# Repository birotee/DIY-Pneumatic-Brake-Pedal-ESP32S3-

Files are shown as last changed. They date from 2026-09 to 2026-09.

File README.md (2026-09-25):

# Jack Pedal

ESP32-S3 pneumatic brake controller using an ADS1220 and a 3.3 V, 0.4-2.4 V, 0-10 bar pressure sensor.

## Build photos

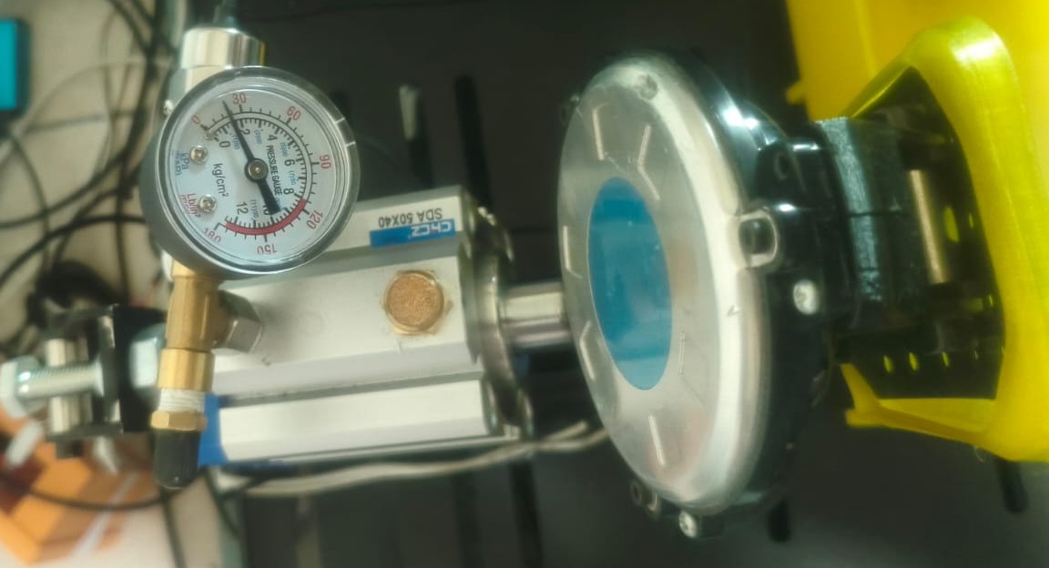
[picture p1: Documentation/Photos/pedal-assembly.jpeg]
Pneumatic brake pedal assembly


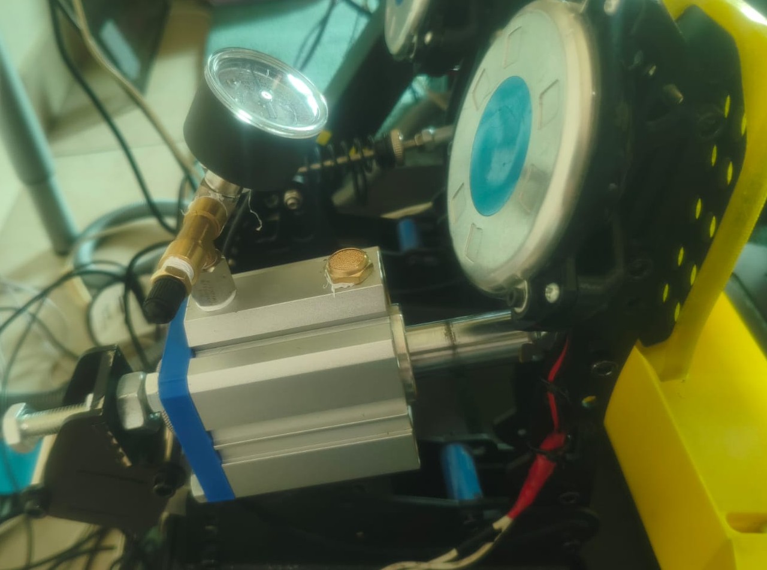
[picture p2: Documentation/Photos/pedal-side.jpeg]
Side view of the pneumatic cylinder and pedal


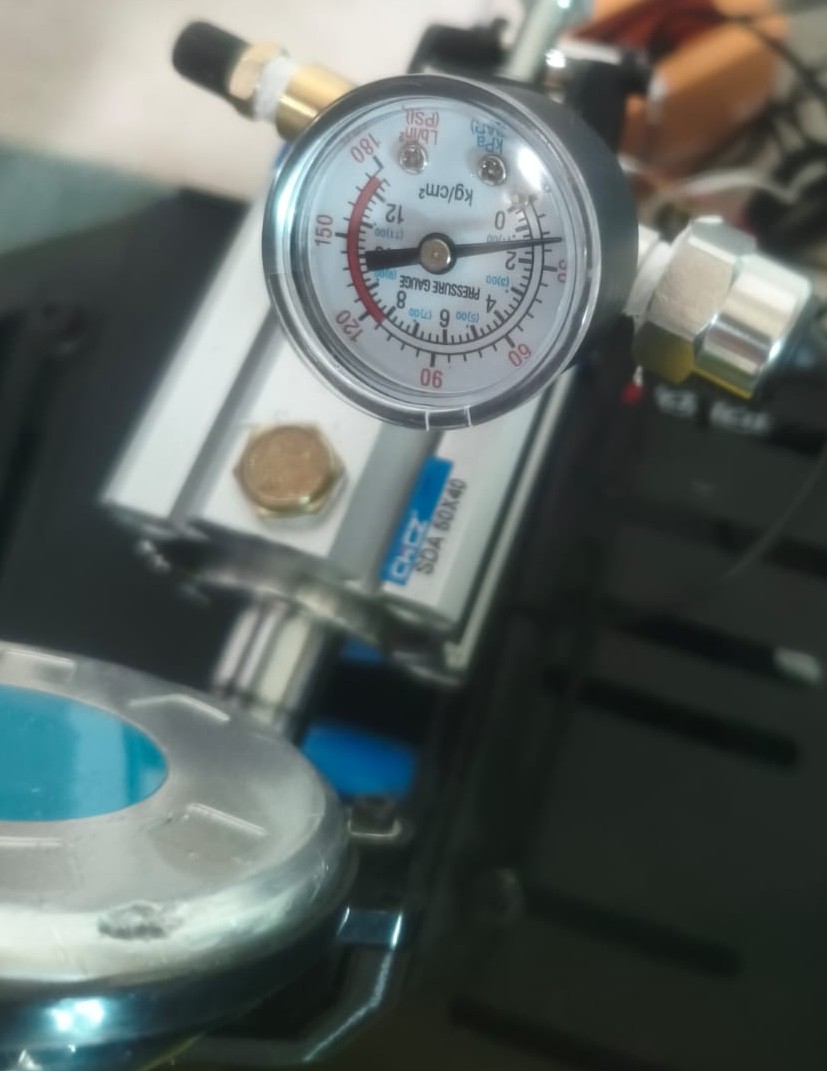
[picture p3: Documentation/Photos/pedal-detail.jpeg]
Pressure gauge and cylinder detail


## Files

- `JackPedal_PC/`: Arduino firmware and bundled ADS1220 library.
- `JackPedalControl.exe`: Windows calibration app.
- `JackPedalControl.cs`: app source; run `Build-Windows-App.ps1` to rebuild on Windows with the .NET Framework compiler.
- `Documentation/`: setup instructions and wiring PDF.
- `Enclosure/`: prototype 108 x 108 x 50 mm enclosure, STL files and editable OpenSCAD source. Read its fit limitations before printing.

## Wiring

| ESP32-S3 | ADS1220 |
| --- | --- |
| 3V3 | AVDD, DVDD, REFP0 |
| GND | AGND/AVSS, DGND, REFN0, CLK |
| GPIO10 | CS |
| GPIO9 | DRDY |
| GPIO13 | SCLK |
| GPIO12 | MISO/DOUT |
| GPIO11 | MOSI/DIN |

Sensor power goes to 3V3, ground to common GND, and signal directly to AIN1. No signal divider. CLK and SCLK are different pins.

## Arduino settings (N16R8)

ESP32S3 Dev Module; Flash 16 MB; QIO 80 MHz; OPI PSRAM; USB-OTG (TinyUSB).
Disable USB CDC, MSC and DFU On Boot. Upload through the COM socket.
Keep all files in `JackPedal_PC/` together when opening the sketch.

## Use

Close Serial Monitor before opening the Windows app. Select the current COM port and connect.
Capture MIN with the pedal released, then capture MAX while holding the desired full-brake pressure steady.
Bottom and top deadzones each support 0-25%; click Apply to save them on the controller.
Defaults are 2% bottom and 8% top: full brake begins at 92% of the calibrated range.
Pressure readings remain independent of calibration and deadzones.
Connect the native USB socket to the PC for game-controller input; the brake uses the Y axis.

## Validation status

Sensor readings and USB gamepad detection were confirmed by the user before the deadzone update.
The Windows app builds and its parser/calibration tests pass. Deadzone arithmetic was checked independently.
The latest firmware includes a fix for Arduino custom-type prototype ordering and still needs a successful user compile/upload and pedal test.
The enclosure is a fit-check prototype; its mesh edges were checked but physical fit is unverified.

## Credits

Based on the Jack-Pneumatic project by LandoCode89.
The bundled ADS1220_WE library was written by Wolfgang (Wolle) Ewald; its source notices are retained.
No new license is assigned by this upload preparation.

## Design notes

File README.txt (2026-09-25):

JACK PEDAL - CURRENT WORKING FILES

JackPedalControl.exe       Windows calibration app (working COM-fix build)
JackPedalControl.cs        Matching C# source
Build-Windows-App.ps1      Rebuild the executable; close it first
JackPedal_PC/              Arduino sketch and required ADS1220 library
Documentation/            Wiring PDF and setup guide

START HERE
1. Read Documentation/Setup.txt and the wiring PDF.
2. Upload JackPedal_PC/JackPedal_PC.ino through the board's COM socket.
3. Close Arduino Serial Monitor, open JackPedalControl.exe, select the current port.
4. Capture released MIN, then MAX at your desired full-brake pressure.
5. Connect the board's USB socket to the PC for game-controller input.

This keeps the known-working code, including USB diagnostics.
Older versions and test sketches were moved to the workspace backups folder.
No calibration data on the ESP32 was changed by this folder cleanup.

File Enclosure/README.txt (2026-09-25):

JACK PEDAL - 108 x 108 x 50 mm OVERALL

Base: 101 x 101 x 47 mm. Lid: 108 x 108 x 11 mm.
The lid overlaps by 8 mm, giving 50 mm assembled height.
3 mm walls/floor/lid top. Slip-over lid, 0.5 mm clearance per side.
Secure lid with tape or an external strap; this is not a snap fit.

BOARD FIT
Expansion board assumed 83 x 83 mm, placed on four 4 mm raised supports.
Use insulating pads as needed and narrow cable ties through floor slots.
Do not tie across components or antenna. No fixed screw posts: hole spacing unknown.
ADS1220 (21 x 21 x 8 mm) mounts UNDER THE LID in the 23 mm wide cradle.
Use a narrow tie through the lid slots to retain it, plus thin insulating pad.
Orient lid so ADC avoids tall connectors on the expansion board.
Internal clearance above expansion-board supports is 40 mm away from ADC.
Reserve 12 mm below lid for ADC/pad/tie, leaving 28 mm locally above supports.
Earlier 60 mm assembled wiring WILL NOT FIT unchanged. Rearrange and measure.
USB notch is 62 mm wide and starts 12 mm above exterior bottom.
Check USB plug height/reach and wire bend clearance before full printing.
Sensor notch is 12 mm wide and starts 25 mm above exterior bottom.

PRINT
STLs use mm. Print base floor-down and lid exterior-face-down as supplied.
Suggested starting settings: 0.2 mm layers, 3 perimeters, 4 top/bottom layers,
15-20% infill. Designed without supports in supplied orientations.
Nonconductive filament only. Not water/dust sealed. Fit/thermal tests pending.
Both meshes passed closed-edge tests; physical fit is NOT guaranteed.
Print a partial-height base first to check board footprint and tie locations.

FILES
JackPedal_Base.stl and JackPedal_Lid.stl: latest 108 mm version.
JackPedal_Enclosure.scad: editable OpenSCAD source.
Layout.png: base/lid plan and clearances.
Mesh_Checks.json: mesh dimensions/check results.

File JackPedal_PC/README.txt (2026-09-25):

JackPedal PC - 3.3V supply, 0.4-2.4V output, 0-10 bar sensor

Open JackPedal_PC.ino with ADS1220_WE.h and ADS1220_WE.cpp alongside it.
Sensor supply + -> ESP32 3V3 (not 5V).
Sensor ground -> common GND.
Sensor output -> ADS1220 AIN1 directly. Remove the old signal divider.
Identify sensor wires from its label; do not assume the old sensor colors.
ADC AVDD, DVDD, REFP0 -> 3V3.
ADC AGND/AVSS, DGND, REFN0 and CLK -> common GND. CLK is separate from SCLK.
CS GPIO10, DRDY GPIO9, SCK GPIO13, MISO GPIO12, MOSI GPIO11.
All SPI and DRDY connections direct; no resistor dividers.

Reference 3.3V, gain 1, PGA bypass, SPI 1 MHz.
Pressure bar = clamp((AIN1 volts - 0.4) * 5, 0, 10).
Windows pressure display remains PSI: bar * 14.5037738 (maximum 145.0 PSI).
Expected signal: 0 bar = 0.4V; 5 bar = 1.4V; 10 bar = 2.4V.
New EEPROM signature resets the previous sensor calibration on first boot.
Capture released MIN then desired full-brake MAX. Progress and filtering retained.

Board: ESP32S3 Dev Module, USB-OTG (TinyUSB), USB CDC On Boot Disabled.
N16R8: Flash 16MB, Flash Mode QIO 80MHz, PSRAM OPI. USB MSC and DFU On Boot Disabled.
UART/CP2102 USB for upload and Windows app, 115200 baud.
Native USB for game controller (brake on Y, other axes neutral).
Close Arduino Serial Monitor before connecting the Windows app.
Select the actual COM port; it may differ from COM6 on a new board.

ADC register verification and missing/zero-data errors retained.
User confirmed sensor readings after replacing the ADS1220 and later confirmed gamepad detection.
USB_DIAG messages remain enabled in this known-working firmware. They are ignored by the app.

BOTTOM / TOP DEADZONES
Upload the updated Arduino sketch before using the new app controls.
Each setting is 0-25 percent of the captured MIN-to-MAX range.
Defaults: bottom 2%, top 8%. Click Apply to save on the ESP32.
Bottom 2%: output stays zero through the first 2% of calibrated range.
Top 8%: output reaches 100% at 92% of calibrated range.
The remaining range is mapped linearly. PSI and voltage are unaffected.
Saved MIN/MAX and response settings are preserved when upgrading this version.
Reset restores deadzones to 2%/8%, alongside calibration/filter defaults.
Old firmware leaves the app deadzone controls disabled; upload the new sketch.
App compiled and parser tests passed; mapping arithmetic checked independently.
Firmware still requires Arduino Verify/upload and a physical pedal test.

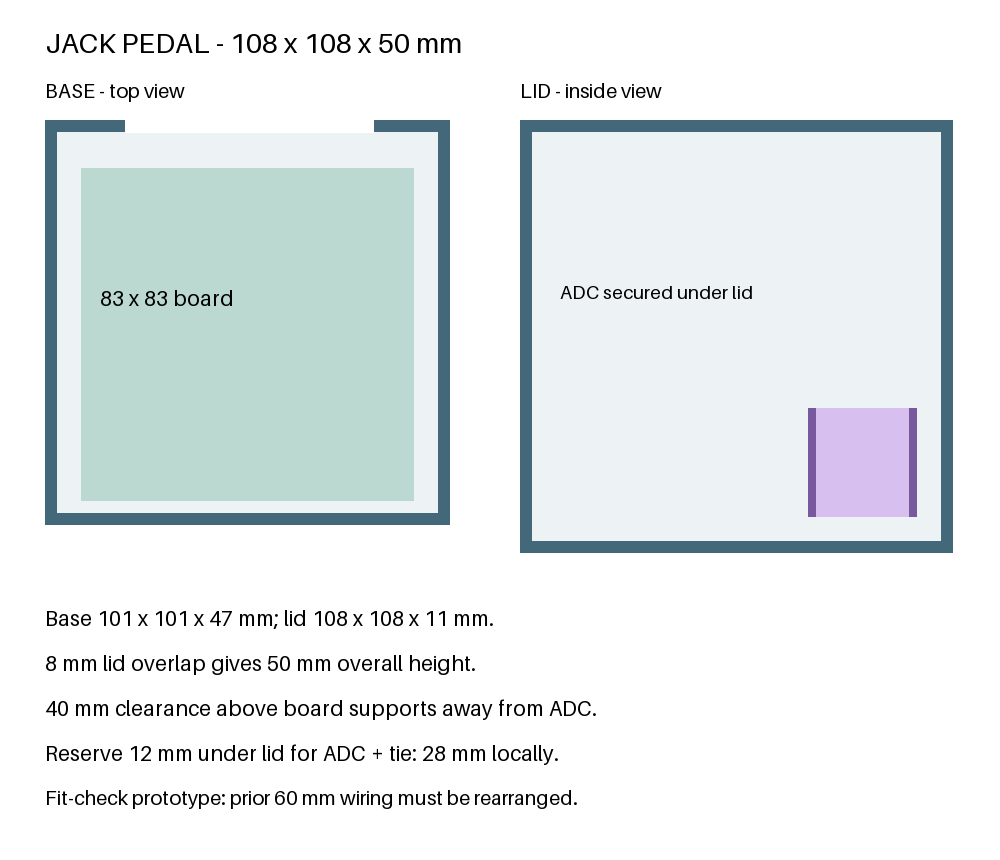
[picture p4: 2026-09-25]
Enclosure/Layout.png

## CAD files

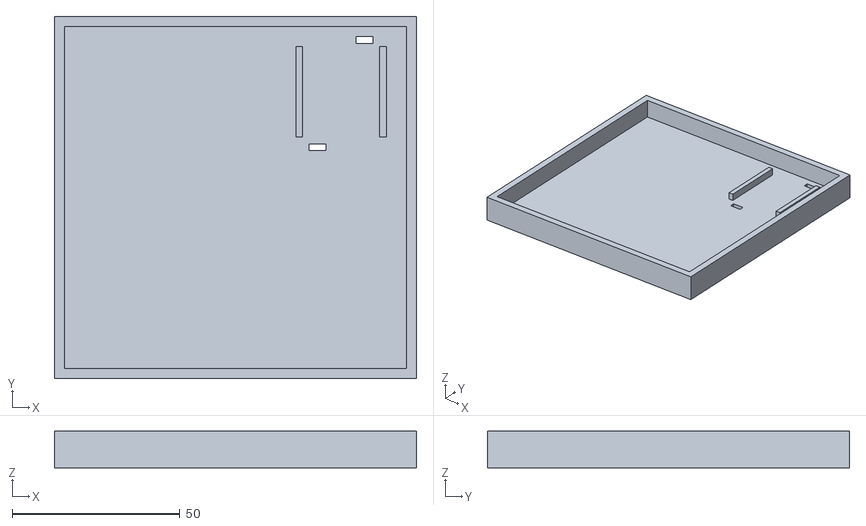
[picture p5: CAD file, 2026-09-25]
Enclosure/JackPedal_Lid.stl
108.0 x 108.0 x 11.0

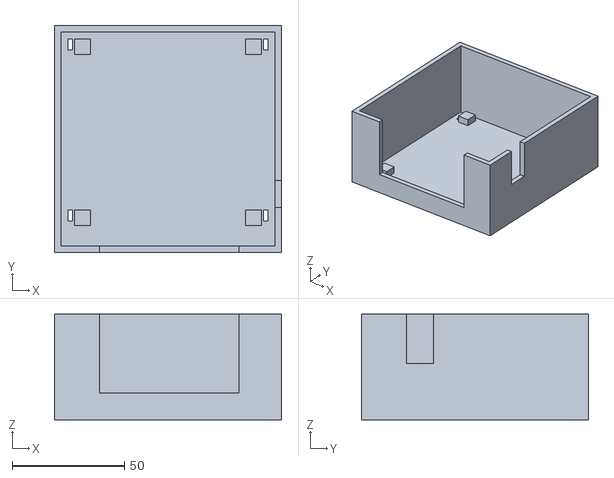
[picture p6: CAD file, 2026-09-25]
Enclosure/JackPedal_Base.stl
101.0 x 101.0 x 47.0

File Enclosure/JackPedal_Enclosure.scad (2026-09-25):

// Units mm. Prototype: board 83x83, Overall assembled enclosure 108x108x50. Internal board clearance 40.
// part: base, lid or layout. Lid prints exterior face down.
part="layout";
module base(){difference(){union(){difference(){translate([0,0,0]) cube([101,101,47]);translate([3,3,3]) cube([95,95,45]);translate([20,-1,12]) cube([62,5,36]);translate([97,20,25]) cube([5,12,23]);}translate([9,12,3]) cube([7,7,4]);translate([9,88,3]) cube([7,7,4]);translate([85,12,3]) cube([7,7,4]);translate([85,88,3]) cube([7,7,4]);}translate([6,14,-1]) cube([2,5,5]);translate([6,90,-1]) cube([2,5,5]);translate([93,14,-1]) cube([2,5,5]);translate([93,90,-1]) cube([2,5,5]);}}
module lid(){difference(){translate([0,0,0]) cube([108,108,11]);translate([3,3,3]) cube([102,102,9]);translate([76,68,-1]) cube([5,2,5]);translate([90,100,-1]) cube([5,2,5]);}}
module lid_complete(){union(){lid();translate([72,72,3]) cube([2,27,3]);translate([97,72,3]) cube([2,27,3]);}}
if(part=="base") base(); else if(part=="lid") lid_complete(); else {base(); translate([120,0,0]) lid_complete();}

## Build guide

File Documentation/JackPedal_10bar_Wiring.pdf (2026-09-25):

# JACK PEDAL

## ESP32-S3 + ADS1220 | 0-10 bar pressure sensor

### Required sensor power: 3.3 V DC

Sensor signal output: 0.4-2.4 V DC = 0-10 bar

Disconnect power before wiring. No resistor dividers are needed.

### 1 SENSOR CONNECTIONS

Sensor terminal | Connect to
Power (+): 3.3 V | ESP32 3V3
Ground (-) | Common GND
OUT: 0.4-2.4 V | ADS1220 AIN1

Use the sensor label to identify wires; do not assume wire colors.

### 2 ADC POWER AND SPI CONNECTIONS

ESP32-S3 | ADS1220
3V3 | AVDD, DVDD, REFP0
GND | AGND, DGND, REFN0
GND | CLK (internal ADC clock)
GPIO10 | CS
GPIO9 | DRDY
GPIO13 | SCLK
GPIO12 | MISO / DOUT
GPIO11 | MOSI / DIN

All grounds must connect together. Power the sensor and ADC at 3.3 V.
Remove old divider resistors on AIN1, MISO and DRDY; connect directly.

### 3 QUICK VOLTAGE CHECK

With power on, measure AIN1 relative to GND:

### 0 bar

0.4 V

### 5 bar

1.4 V

| 10 bar
2.4 V

### USB AND SOFTWARE

UART/CP2102 USB: upload firmware and connect the Windows app. Native USB: game controller. Close Serial Monitor before using the app. Use the 10 bar firmware; capture MIN, then MAX. 10 bar = about 145 PSI.

JackPedal_PC | Direct AIN1 input | Reference 3.3 V | SPI 1 MHz

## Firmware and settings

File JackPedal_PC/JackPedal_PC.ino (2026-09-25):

 
/*
 PC APP VERSION: restored from your saved PC-compatible firmware.
 UART/CP2102: app connection at 115200; native USB: gamepad.
 ADC AVDD/DVDD/REFP0 tied -> 3V3 ONLY. Sensor supply -> 3V3.
 All grounds common; REFN0 -> GND.
 Sensor signal -> AIN1 directly; remove the old resistor divider.
 ADC input is 0.4..2.4V for the 0..10 bar sensor.
 CS10, DRDY9, SCK13, MISO12, MOSI11, direct 3.3V logic.
 No resistors/dividers on MISO or DRDY. No divider on AIN1.
 Calibration/filtering uses Windows app; no OLED/buttons required.
 New EEPROM signature resets incompatible old calibration.
 Built-in gamepad retains its standard descriptor (Y brake, others neutral).
*/
#include <USB.h>
#include <USBHIDGamepad.h>
#include <SPI.h>
#include "ADS1220_WE.h"
#include <EEPROM.h>

// Jack Pneumatic ESP32-S3-DevKitC-1 N16R8 BRAKE-ONLY controller.
// Arduino settings: ESP32S3 Dev Module, USB Mode = USB-OTG (TinyUSB),
// USB CDC On Boot = Disabled, Flash Size = 16MB, PSRAM = OPI PSRAM.
// Native USB port: Windows game controller.  UART/CP2102 port: upload +
// Windows app telemetry.  This keeps joystick HID separate from Serial data.

#if !defined(CONFIG_IDF_TARGET_ESP32S3)
#error "This firmware requires an ESP32-S3."
#endif

// Native USB HID requires TinyUSB, not the hardware CDC/JTAG mode.
#if !defined(ARDUINO_USB_MODE) || ARDUINO_USB_MODE != 0
#error "Select Tools > USB Mode > USB-OTG (TinyUSB), then upload again."
#endif
#if ARDUINO_USB_CDC_ON_BOOT
#error "USB CDC On Boot is ENABLED. Set Tools > USB CDC On Boot > Disabled."
#endif
#if ARDUINO_USB_MSC_ON_BOOT
#error "USB MSC On Boot is ENABLED. Set Tools > USB MSC On Boot > Disabled."
#endif
#if ARDUINO_USB_DFU_ON_BOOT
#error "USB DFU On Boot is ENABLED. Set Tools > USB DFU On Boot > Disabled."
#endif

#define ADS1220_CS_PIN 10
#define ADS1220_DRDY_PIN 9
#define SPI_SCK 13
#define SPI_MISO 12
#define SPI_MOSI 11

// Set to 0 while testing only the ESP32-S3 USB connection without the ADS1220.
// Change to 1 only after all ADS1220 wires in the diagram are connected.
#define ADS1220_PRESENT 1

#define EEPROM_SIZE 64
#define EEPROM_MAGIC 0x4A503130UL
#define JOYSTICK_SEND_MS 4
#define TELEMETRY_MS 50
#define DEADBAND_COUNTS 5084
#define CALIBRATION_MS 4000
#define ADC_TIMEOUT_MS 500
#define ERROR_REPORT_MS 500
#define COMMAND_BUFFER_LEN 120

constexpr float ADC_REFERENCE_V = 3.3f;
constexpr float SENSOR_ZERO_V = 0.4f;
constexpr float SENSOR_FULL_V = 2.4f;
constexpr float SENSOR_MAX_BAR = 10.0f;
constexpr float PSI_PER_BAR = 14.5037738f;

#define BRAKE_ZERO_COUNTS 1016801
#define BRAKE_MAX_COUNTS 6100806
#define ADC_MAX_SIGNED 8388607

// Built-in ESP32-S3 USB gamepad. The brake is sent on the Y axis.
USBHIDGamepad gamepad;
bool usbStarted = false;
bool lastHidReportOK = false;

// Expose read-only register verification without changing the ADC library.
class CheckedADS1220 : public ADS1220_WE {
public:
  CheckedADS1220() : ADS1220_WE(&SPI, ADS1220_CS_PIN, ADS1220_DRDY_PIN, false, true) {}
  uint8_t config(uint8_t index) { return readRegister(index); }
};
CheckedADS1220 ads;

// Declare the custom type and prototype before Arduino-generated prototypes.
enum CalibrationMode { CAL_NONE, CAL_MIN, CAL_MAX };
void beginCalibration(int axis, CalibrationMode mode);

struct Settings {
  uint32_t magic;
  int32_t minimum[4];
  int32_t maximum[4];
  uint8_t alpha[4];
};

Settings settings;
// Separate EEPROM record preserves existing calibration and filter settings.
struct Deadzones { uint32_t magic; uint8_t bottom; uint8_t top; uint8_t reserved[2]; };
Deadzones deadzones;
constexpr uint32_t DEADZONE_MAGIC = 0x445A3031UL;
static_assert(sizeof(Settings) == 40, "Check legacy EEPROM layout");
static_assert(sizeof(Settings) + sizeof(Deadzones) <= EEPROM_SIZE, "EEPROM too small");
void saveDeadzones() {
  deadzones.magic = DEADZONE_MAGIC;
  EEPROM.put(sizeof(Settings), deadzones);
  EEPROM.commit();
}
void loadDeadzones() {
  EEPROM.get(sizeof(Settings), deadzones);
  if (deadzones.magic != DEADZONE_MAGIC || deadzones.bottom > 25 || deadzones.top > 25) {
    deadzones = {DEADZONE_MAGIC, 2, 8, {0, 0}};
    saveDeadzones();
  }
}
long mapBrake(int32_t value) {
  const int64_t low = settings.minimum[1], high = settings.maximum[1];
  const int64_t span = high - low;
  if (span <= 0) return 0;
  // Percentages are taken from the complete calibrated range.
  const int64_t effectiveLow = low + span * deadzones.bottom / 100;
  const int64_t effectiveHigh = high - span * deadzones.top / 100;
  if (effectiveHigh <= effectiveLow || value <= effectiveLow) return 0;
  if (value >= effectiveHigh) return 65535;
  return (long)(((int64_t)value - effectiveLow) * 65535 / (effectiveHigh - effectiveLow));
}

bool adcInitialized = false;
const char *adcFault = "ADS1220_INIT";
bool zeroSamples = false;
unsigned long zeroSince = 0;
bool adcFresh = false;
unsigned long lastAdcSample = 0;
int32_t rawBrake = 0;
int32_t filtered[4] = { 0, 0, 0, 0 };
int32_t stable[4] = { 0, 0, 0, 0 };
bool filterReady = false;
String commandLine;
bool lastTelemetryWasError = false;
unsigned long lastErrorReport = 0;


CalibrationMode calibrationMode = CAL_NONE;
int calibrationAxis = -1;
int32_t calibrationValue = 0;
unsigned long calibrationStarted = 0;

void defaultsForAxis(int axis) {
  settings.minimum[axis] = axis == 1 ? BRAKE_ZERO_COUNTS : 0;
  settings.maximum[axis] = axis == 1 ? BRAKE_MAX_COUNTS : ADC_MAX_SIGNED;
  settings.alpha[axis] = 10;
}

void saveSettings() {
  settings.magic = EEPROM_MAGIC;
  EEPROM.put(0, settings);
  EEPROM.commit();
}

void loadSettings() {
  EEPROM.get(0, settings);
  if (settings.magic != EEPROM_MAGIC) {
    for (int i = 0; i < 4; ++i) defaultsForAxis(i);
    saveSettings();
    return;
  }
  for (int i = 0; i < 4; ++i) {
    if (settings.alpha[i] < 5 || settings.alpha[i] > 100)
      settings.alpha[i] = 10;
  }
}

// Map raw sensor value to 0..65535 game axis range.
// Returns 0 if range is invalid (prevents division by zero).
long mapAxis(int32_t value, int32_t low, int32_t high) {
  if (high <= low) return 0;
  int64_t result = (int64_t)(value - low) * 65535 / (high - low);
  return constrain((long)result, 0L, 65535L);
}

// Convert raw ADC counts to brake pressure in PSI.
float brakePsi(int32_t raw) {
  const float adcV = (float)raw * ADC_REFERENCE_V / 8388608.0f;
  const float sensorV = adcV; // Direct connection: no divider.
  const float bar = constrain((sensorV - SENSOR_ZERO_V) * SENSOR_MAX_BAR /
                              (SENSOR_FULL_V - SENSOR_ZERO_V), 0.0f, SENSOR_MAX_BAR);
  return bar * PSI_PER_BAR; // Keep the Windows telemetry pressure field in PSI.
}

void sendConfig() {
  Serial.printf("CONFIG,%ld,%ld,%u,%ld,%ld,%u,%ld,%ld,%u,%ld,%ld,%u\n",
                settings.minimum[0], settings.maximum[0], settings.alpha[0],
                settings.minimum[1], settings.maximum[1], settings.alpha[1],
                settings.minimum[2], settings.maximum[2], settings.alpha[2],
                settings.minimum[3], settings.maximum[3], settings.alpha[3]);
  Serial.printf("DZ,%u,%u\n", deadzones.bottom, deadzones.top);
}

void reply(const char *status, const char *message) {
  Serial.print(status);
  Serial.print(',');
  Serial.println(message);
}

void beginCalibration(int axis, CalibrationMode mode) {
  if (axis != 1 || calibrationMode != CAL_NONE || !adcFresh || rawBrake <= 0) {
    reply("ERR", "CALIBRATION_UNAVAILABLE");
    return;
  }
  calibrationAxis = axis;
  calibrationMode = mode;
  calibrationValue = (mode == CAL_MIN) ? INT32_MAX : INT32_MIN;
  calibrationStarted = millis();
  Serial.printf("CAL,START,%d,%s\n", axis, mode == CAL_MIN ? "MIN" : "MAX");
}

void handleCommand(String line) {
  line.trim();
  if (!line.length()) return;

  if (line == "HELLO" || line == "GET") {
    // The app answers HELLO with GET: GET must not send HELLO again.
    if (line == "HELLO") reply("HELLO", "JACK_PEDAL_PC,1");
    sendConfig();
    return;
  }

  int p1 = line.indexOf(',');
  int p2 = line.indexOf(',', p1 + 1);
  String action = p1 < 0 ? line : line.substring(0, p1);
  if (action == "DEADZONE") {
    unsigned int bottom, top; char extra;
    if (sscanf(line.c_str(), "DEADZONE,%u,%u%c", &bottom, &top, &extra) != 2 || bottom > 25 || top > 25) {
      reply("ERR", "BAD_DEADZONE"); return;
    }
    if (calibrationMode != CAL_NONE) { reply("ERR", "DEADZONE_BUSY"); return; }
    deadzones.bottom = bottom; deadzones.top = top;
    saveDeadzones(); reply("OK", "DEADZONE_SAVED"); sendConfig(); return;
  }
  int axis = p1 < 0 ? -1 : line.substring(p1 + 1, p2 < 0 ? line.length() : p2).toInt();

  if (action == "MIN") {
    beginCalibration(axis, CAL_MIN);
    return;
  }
  if (action == "MAX") {
    beginCalibration(axis, CAL_MAX);
    return;
  }
  if (action == "CANCEL") {
    calibrationMode = CAL_NONE;
    calibrationAxis = -1;
    reply("OK", "CANCELLED");
    return;
  }
  if (action == "RESET" && axis == 1) {
    defaultsForAxis(axis);
    deadzones.bottom = 2; deadzones.top = 8; saveDeadzones();
    saveSettings();
    reply("OK", "RESET");
    sendConfig();
    return;
  }
  if (action == "ALPHA" && axis == 1 && p2 >= 0) {
    int value = line.substring(p2 + 1).toInt();
    value = constrain(((value + 2) / 5) * 5, 5, 100);
    settings.alpha[axis] = value;
    saveSettings();
    reply("OK", "ALPHA");
    sendConfig();
    return;
  }

  reply("ERR", "BAD_COMMAND");
}

void readCommands() {
  while (Serial.available()) {
    char c = (char)Serial.read();
    if (c == '\n') {
      handleCommand(commandLine);
      commandLine = "";
    } else if (c != '\r' && commandLine.length() < COMMAND_BUFFER_LEN) {
      commandLine += c;
    }
  }
}

void updateCalibration() {
  if (calibrationMode == CAL_NONE) return;

  int32_t value = stable[calibrationAxis];
  if (calibrationMode == CAL_MIN) {
    calibrationValue = min(calibrationValue, value);
  } else {
    calibrationValue = max(calibrationValue, value);
  }

  unsigned long elapsed = millis() - calibrationStarted;
  if (elapsed < CALIBRATION_MS) return;

  // Validation: ensure min/max are sensible.
  if (calibrationValue <= 0 ||
      (calibrationMode == CAL_MAX && calibrationValue <= settings.minimum[calibrationAxis] + DEADBAND_COUNTS)) {
    calibrationMode = CAL_NONE;
    calibrationAxis = -1;
    reply("ERR", "INVALID_CALIBRATION_CHECK_ADC");
    return;
  }

  // Apply calibration.
  if (calibrationMode == CAL_MIN) {
    settings.minimum[calibrationAxis] = calibrationValue;
  } else {
    settings.maximum[calibrationAxis] = calibrationValue;
  }
  saveSettings();

  Serial.printf("CAL,DONE,%d,%s,%ld\n", calibrationAxis,
                calibrationMode == CAL_MIN ? "MIN" : "MAX", calibrationValue);
  calibrationMode = CAL_NONE;
  calibrationAxis = -1;
  sendConfig();
}

void setup() {
  // Start HID before sensor initialisation, so Windows sees the controller even
  // if the ADS1220 wiring needs attention.
  Serial.begin(115200);
  USB.productName("Jack Pedal Brake");
  USB.manufacturerName("Jack Pedal");
  gamepad.begin(); // Register HID before starting the USB device.
  usbStarted = USB.begin();
  Serial.printf("USB_DIAG,begin=%d,mounted=%d\n", usbStarted, (bool)USB);
  commandLine.reserve(COMMAND_BUFFER_LEN + 8);

  EEPROM.begin(EEPROM_SIZE);
  loadSettings();
  loadDeadzones();

#if ADS1220_PRESENT
  SPI.begin(SPI_SCK, SPI_MISO, SPI_MOSI, ADS1220_CS_PIN);
  ads.setSPIClockSpeed(1000000);
  adcInitialized = ads.init();
  if (!adcInitialized) {
    reply("ERR", "ADS1220_INIT");
  }

  if (adcInitialized) {
    ads.setVRefSource(ADS1220_VREF_REFP0_REFN0);
    ads.setVRefValue_V(ADC_REFERENCE_V);
    ads.setGain(ADS1220_GAIN_1);
    ads.bypassPGA(true);
    ads.setDataRate(ADS1220_DR_LVL_6);
    ads.setOperatingMode(ADS1220_TURBO_MODE);
    ads.setConversionMode(ADS1220_CONTINUOUS);
    ads.setFIRFilter(ADS1220_50HZ_60HZ);
    pinMode(ADS1220_DRDY_PIN, INPUT);
    ads.setCompareChannels(ADS1220_MUX_1_AVSS);
    ads.setNonBlockingMode(true);

    // AIN1/AVSS, gain 1, PGA bypass = 0x91; turbo continuous = 0xD4;
    // REFP0/REFN0 and FIR setting = 0x50; IDAC/DRDY configuration = 0x00.
    const uint8_t expected[4] = {0x91, 0xD4, 0x50, 0x00};
    for (uint8_t i = 0; i < 4; ++i) {
      const uint8_t actual = ads.config(i);
      Serial.printf("ADC_REG,%u,%02X,%02X\n", i, actual, expected[i]);
      if (actual != expected[i]) {
        adcInitialized = false;
        adcFault = "ADS1220_CONFIG_MISMATCH";
      }
    }

    if (adcInitialized) {
      ads.start();
    }
  }
#endif

  reply("HELLO", "JACK_PEDAL_PC,1");
}

void loop() {
  static unsigned long lastJoystick = 0, lastTelemetry = 0;


  // Always responsive to commands.
  readCommands();

  bool gotSample = false;

#if ADS1220_PRESENT
  if (adcInitialized && digitalRead(ADS1220_DRDY_PIN) == LOW) {
    rawBrake = ads.getRawData(); // Nonblocking; DRDY already asserted.

    if (rawBrake == 0) {
      if (!zeroSamples) {
        zeroSamples = true;
        zeroSince = millis();
      }
    } else {
      zeroSamples = false;
    }

    lastAdcSample = millis();
    gotSample = true;

    if (!adcFresh) {
      filterReady = false;
    }
    adcFresh = true;
  }
#endif

  // Process new sample if available.
  if (gotSample) {
    if (!filterReady) {
      filtered[1] = stable[1] = rawBrake;
      filterReady = true;
    }

    // Apply exponential moving average filter.
    filtered[1] += (int32_t)(((int64_t)rawBrake - filtered[1]) * settings.alpha[1] / 100);

    // Update stable value only when deadband threshold is crossed.
    if (abs(filtered[1] - stable[1]) >= DEADBAND_COUNTS) {
      stable[1] = filtered[1];
    }

    if (rawBrake > 0) {
      updateCalibration();
    }
  }

  // Check for ADC loss (timeout, no data, etc.).
  if (!adcInitialized || !filterReady || 
      millis() - lastAdcSample > ADC_TIMEOUT_MS || 
      (zeroSamples && millis() - zeroSince > ADC_TIMEOUT_MS)) {
    adcFresh = false;

    // Cancel calibration if ADC is lost.
    if (calibrationMode != CAL_NONE) {
      calibrationMode = CAL_NONE;
      calibrationAxis = -1;
      reply("ERR", "ADC_LOST_CALIBRATION_CANCELLED");
    }
  }

  // Read time after commands and sample processing, which can start calibration.
  const unsigned long now = millis();
  const unsigned long elapsed = now - calibrationStarted;
  const unsigned long remaining = calibrationMode == CAL_NONE || elapsed >= CALIBRATION_MS
                                  ? 0UL : CALIBRATION_MS - elapsed;

  // Send gamepad report every JOYSTICK_SEND_MS.
  if (now - lastJoystick >= JOYSTICK_SEND_MS) {
    // Map brake pressure to signed 8-bit axis range: -127 (no brake) to +127 (full brake).
    uint16_t brake = adcFresh ? mapBrake(stable[1]) : 0;
    // Convert 0..65535 to -127..+127: first scale to 0..254, then subtract 127.
    int8_t yAxis = (int8_t)((int32_t)brake * 254 / 65535 - 127);
    lastHidReportOK = usbStarted && (bool)USB && gamepad.leftStick(0, yAxis);
    lastJoystick = now;
  }

  // Send telemetry every TELEMETRY_MS.
  if (Serial && now - lastTelemetry >= TELEMETRY_MS) {
    if (!adcFresh) {
      // Repeat faults for late app connections; send the error AFTER placeholder data.
      if (!lastTelemetryWasError || now - lastErrorReport >= ERROR_REPORT_MS) {
        const char *errorMsg = !adcInitialized ? adcFault : 
                               (zeroSamples ? "ADS1220_ZERO_DATA_CHECK_SPI_AIN1" : "ADS1220_NO_DATA");
        Serial.printf("T,0,0,0,0,0,0,0,0,0.0,-1,0\n");
        reply("ERR", errorMsg);
        lastErrorReport = now;
        lastTelemetryWasError = true;
      }
    } else {
      lastTelemetryWasError = false;
      Serial.printf("T,%ld,%ld,%ld,%ld,%ld,%ld,%ld,%ld,%.1f,%d,%lu\n",
                    stable[0], stable[1], stable[2], stable[3],
                    mapAxis(stable[0], settings.minimum[0], settings.maximum[0]),
                    mapBrake(stable[1]),
                    mapAxis(stable[2], settings.minimum[2], settings.maximum[2]),
                    mapAxis(stable[3], settings.minimum[3], settings.maximum[3]),
                    brakePsi(stable[1]), calibrationAxis,
                    remaining);
    }
    lastTelemetry = now;
  }

  // Periodic diagnostics are ignored by the Windows app; view via COM Serial Monitor.
  static unsigned long lastUsbDiagnostic = 0;
  if (now - lastUsbDiagnostic >= 2000) {
    Serial.printf("USB_DIAG,begin=%d,mounted=%d,report=%d\n",
                  usbStarted, (bool)USB, lastHidReportOK);
    lastUsbDiagnostic = now;
  }
  delay(1);
}
 

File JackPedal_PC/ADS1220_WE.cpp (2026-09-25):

/*****************************************
* This is a library for the 24 bit, 4 channel ADS1220 A/D Converter
*
* I added example sketches which should enable you to use the library. 
*
* You are free to use it, change it or build on it. In case you like 
* it, it would be cool if you give it a star.
* 
* If you find bugs, please inform me!
* 
* Written by Wolfgang (Wolle) Ewald
*
* On my website you find:
*
*   1) An article about the ADS1220 and the use of this library
*      https://wolles-elektronikkiste.de/ads1220-4-kanal-24-bit-a-d-wandler  (German) 
*      https://wolles-elektronikkiste.de/en/4-channel-24-bit-adc-ads1220     (English)
*
*   2) An article how to use the ADS1220 for typical applications, such as thermocouples, 
*      NTCs, RTDs or Wheatstone bridges:
*      https://wolles-elektronikkiste.de/ads1220-teil-2-anwendungen          (German)
*      https://wolles-elektronikkiste.de/en/ads1220-part-2-applications      (English)
*
*******************************************/

#include "ADS1220_WE.h"

/* Constructors */

ADS1220_WE::ADS1220_WE(int cs, int drdy, bool pc, bool spiInit) 
    : _spi(&SPI)
    , csPin(cs)
    , drdyPin(drdy)
    , spiPinsChanged(pc)
    , spiInitialized(spiInit) 
    {} // intentionally empty}

ADS1220_WE::ADS1220_WE(SPIClass *s, int cs, int drdy, bool pc, bool spiInit) 
    : _spi(s)
    , csPin(cs)
    , drdyPin(drdy)
    , spiPinsChanged(pc)
    , spiInitialized(spiInit) 
    {} // intentionally empty}
    
ADS1220_WE::ADS1220_WE(SPIClass *s, int cs, int drdy, int mosi, int miso, int sclk, bool pc, bool spiInit) 
    : _spi(s)
    , csPin(cs)
    , drdyPin(drdy)
    , mosiPin(mosi)
    , misoPin(miso)
    , sclkPin(sclk)
    , spiPinsChanged(pc)
    , spiInitialized(spiInit)
    {} // intentionally empty}
    
/* Commands */

uint8_t ADS1220_WE::init(){
    vRef = 2.048;
    gain = 1; 
    refMeasurement = false; 
    convMode = ADS1220_SINGLE_SHOT;
    if(!(drdyPin < 0)){
        pinMode(drdyPin, INPUT);
    }
 
#if defined(ESP32)
    if(spiPinsChanged){
        if(!spiInitialized){
            _spi->begin(sclkPin, misoPin, mosiPin, csPin);
            spiInitialized = true;
        }
    } else {
        if(!spiInitialized){
            _spi->begin();
            spiInitialized = true;
        }
    }
#elif defined(ARDUINO_ARCH_STM32)
    if(spiPinsChanged){
        _spi->setMISO(misoPin);
        _spi->setMOSI(mosiPin);
        _spi->setSCLK(sclkPin);
    }
    if(!spiInitialized){
        _spi->begin();
        spiInitialized = true;
    }
#else   
    if(!spiInitialized){
        _spi->begin();
        spiInitialized = true;
    }
#endif

    setSPIClockSpeed(spiClock);
    if(!(csPin < 0)){
        pinMode(csPin, OUTPUT);
        digitalWrite(csPin, HIGH);
    }
    reset(); 
    start();
    uint8_t ctrlVal = 0;
    bypassPGA(true); // just a test if the ADS1220 is connected
    ctrlVal = readRegister(ADS1220_CONF_REG_0);
    bypassPGA(false);
    setNonBlockingMode(false);
    if(ctrlVal == 1){
      return true;
    }
    else return false;
}

void ADS1220_WE::start(){
    command(ADS1220_START);
}

void ADS1220_WE::reset(){
    command(ADS1220_RESET);
    delay(1);
}

void ADS1220_WE::powerDown(){
    command(ADS1220_PWRDOWN);
}

/* Configuration Register 0 settings */

void ADS1220_WE::setCompareChannels(ads1220Mux mux){
    if((mux == ADS1220_MUX_REFPX_REFNX_4) || (mux == ADS1220_MUX_AVDD_M_AVSS_4)){
        gain = 1;    // under these conditions gain is one by definition 
        refMeasurement = true; 
    }
    else{            // otherwise read gain from register
        regValue = readRegister(ADS1220_CONF_REG_0);
        regValue = regValue & 0x0E;
        regValue = regValue>>1;
        gain = 1 << regValue;
        refMeasurement = false;
    }
    regValue = readRegister(ADS1220_CONF_REG_0);
    regValue &= ~0xF1;
    regValue |= mux;
    regValue |= !(doNotBypassPgaIfPossible & 0x01);
    writeRegister(ADS1220_CONF_REG_0, regValue);
    if((mux >= 0x80) && (mux <=0xD0)){
        if(gain > 4){
            gain = 4;           // max gain is 4 if single-ended input is chosen or PGA is bypassed
        }
        forcedBypassPGA();
    }
}

void ADS1220_WE::setGain(ads1220Gain enumGain){
    regValue = readRegister(ADS1220_CONF_REG_0);
    ads1220Mux mux = (ads1220Mux)(regValue & 0xF0);
    regValue &= ~0x0E;
    regValue |= enumGain;
    writeRegister(ADS1220_CONF_REG_0, regValue);
    
    gain = 1<<(enumGain>>1);
    if((mux >= 0x80) && (mux <=0xD0)){
        if(gain > 4){
            gain = 4;   // max gain is 4 if single-ended input is chosen or PGA is bypassed
        }
        forcedBypassPGA();
    }
}

uint8_t ADS1220_WE::getGainFactor(){
    return gain;
}

void ADS1220_WE::bypassPGA(bool bypass){
    regValue = readRegister(ADS1220_CONF_REG_0);
    regValue &= ~0x01;
    regValue |= bypass;
    doNotBypassPgaIfPossible = !(bypass & 0x01);
    writeRegister(ADS1220_CONF_REG_0, regValue);
}

bool ADS1220_WE::isPGABypassed(){
    regValue = readRegister(ADS1220_CONF_REG_0);
    return regValue & 0x01;
}

/* Configuration Register 1 settings */

void ADS1220_WE::setDataRate(ads1220DataRate rate){
    regValue = readRegister(ADS1220_CONF_REG_1);
    regValue &= ~0xE0;
    regValue |= rate;
    writeRegister(ADS1220_CONF_REG_1, regValue);
}

void ADS1220_WE::setOperatingMode(ads1220OpMode mode){
    regValue = readRegister(ADS1220_CONF_REG_1);
    regValue &= ~0x18;
    regValue |= mode;
    writeRegister(ADS1220_CONF_REG_1, regValue);
}

void ADS1220_WE::setConversionMode(ads1220ConvMode mode){
    convMode = mode;
    regValue = readRegister(ADS1220_CONF_REG_1);
    regValue &= ~0x04;
    regValue |= mode;
    writeRegister(ADS1220_CONF_REG_1, regValue);
}

void ADS1220_WE::enableTemperatureSensor(bool enable){
    regValue = readRegister(ADS1220_CONF_REG_1);
    if(enable){
        regValue |= 0x02;
    }
    else{
        regValue &= ~0x02;
    }
    writeRegister(ADS1220_CONF_REG_1, regValue);
}

void ADS1220_WE::enableBurnOutCurrentSources(bool enable){
    regValue = readRegister(ADS1220_CONF_REG_1);
    if(enable){
        regValue |= 0x01;
    }
    else{
        regValue &= ~0x01;
    }
    writeRegister(ADS1220_CONF_REG_1, regValue);
}

/* Configuration Register 2 settings */

void ADS1220_WE::setVRefSource(ads1220VRef vRefSource){
    regValue = readRegister(ADS1220_CONF_REG_2);
    regValue &= ~0xC0;
    regValue |= vRefSource;
    writeRegister(ADS1220_CONF_REG_2, regValue);
}

void ADS1220_WE::setFIRFilter(ads1220FIR fir){
    regValue = readRegister(ADS1220_CONF_REG_2);
    regValue &= ~0x30;
    regValue |= fir;
    writeRegister(ADS1220_CONF_REG_2, regValue);
}

void ADS1220_WE::setLowSidePowerSwitch(ads1220PSW psw){
    regValue = readRegister(ADS1220_CONF_REG_2);
    regValue &= ~0x08;
    regValue |= psw;
    writeRegister(ADS1220_CONF_REG_2, regValue);
}
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
